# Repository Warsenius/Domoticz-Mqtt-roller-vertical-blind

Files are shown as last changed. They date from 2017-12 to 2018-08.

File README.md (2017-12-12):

# Domoticz-Mqtt-roller-vertical-blind
wifi controlled window blinds using mqtt controlled by domoticz

This is my automated window blinds project that lets Domoticz open and close my vertical blinds.
A steppermotor is controlled by a Wemos D1 mini which receives its commands from Domoticz using MQTT over wifi.

A MQTT server is needed for Domoticz and the Wemos board to connect to.
To set this up please see the the [Domoticz wiki](https://www.domoticz.com/wiki/MQTT)

The LamellenStudie_Wemos file is uploaded to the Wemos board.

In domoticz a Virtual switch is created (named LamellenStudie in this code) of type Blinds Percentage.
This switch is assigned to a floorplan(example) and to a roomplan(Lamellen).
Domoticz will then send out any any changes done to the Virtual switch to the MQTT topic domoticz/out/example/Lamellen where the Wemos board will subscribe to.

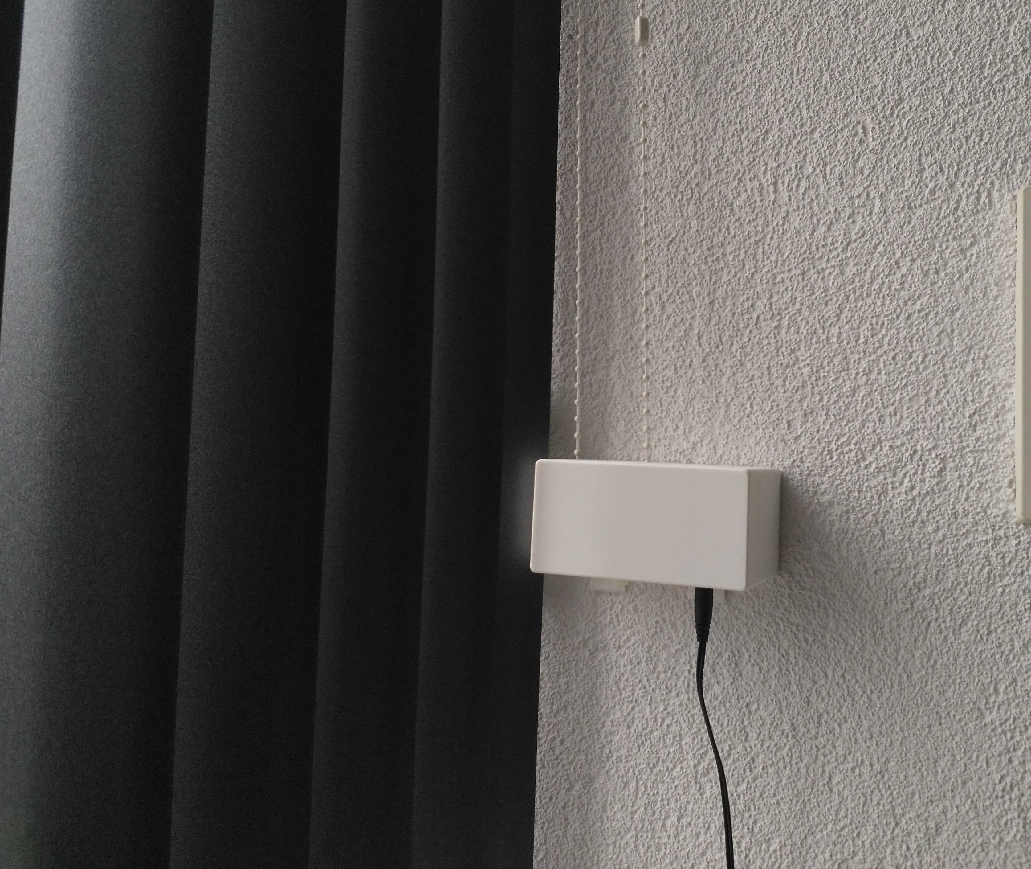
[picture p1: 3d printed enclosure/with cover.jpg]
finished product


## Connecting the parts

I am using the following parts:
1. Wemos D1 mini
1. EasyDriver - Stepper Motor Driver
1. 12 to 5 volt converter [Fine](https://blog.yavilevich.com/2017/03/efficient-dc-12v-to-5v-conversion-for-low-power-electronics-evaluation-of-six-modules/)
1. 2.1 DC power socket
1. 17HS2408 4-lead Nema 17 Steppermotor
1. N/O reed switch (normal open)
1. [Parametric ball chain pulley](https://www.thingiverse.com/thing:3147)
1. [3D printed case](https://github.com/Warsenius/Domoticz-Mqtt-roller-vertical-blind/tree/master/3d%20printed%20enclosure)
1. Tesa powerstrip (to mount case to wall)

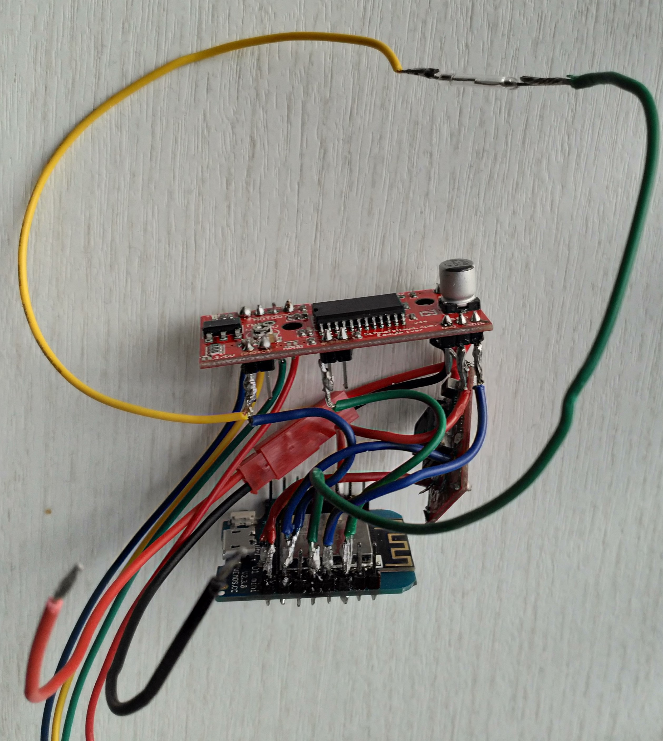
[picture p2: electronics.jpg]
Electronics


The Easydriver board has a build in 12 to 5 volt converter, however it gets really warm and using the Fine converter lowered to idle power usage from 0.11 to 0.04 ampere (at 12volt)

The reed switch is optional, it works as a stop limit using a tiny magnet on the ball chain.

## Follow the Sun

In domoticz i have set up the script "[script_device_blinds_follow_sun_script.lua](https://github.com/Warsenius/Domoticz-Mqtt-roller-vertical-blind/blob/master/script_device_blinds_follow_sun_script.lua)"
This will use the [angle of the sun](http://www.domoticz.com/wiki/Real-time_solar_data_without_any_hardware_sensor_:_azimuth,_Altitude,_Lux_sensor...) and [strenght of the sun](https://www.domoticz.com/wiki/Virtual_weather_devices) (pulled from Weather Underground) to turn the blinds.
It also changes the angle of the blinds if the tv\pc is on and checks if the 'Lamellen Handmatig' virtual switch is on (disabling the script)

the code include's a 'privacy' virtual switch which will close the blinds to position 2 or 14(depending on what is closest) when enabled.

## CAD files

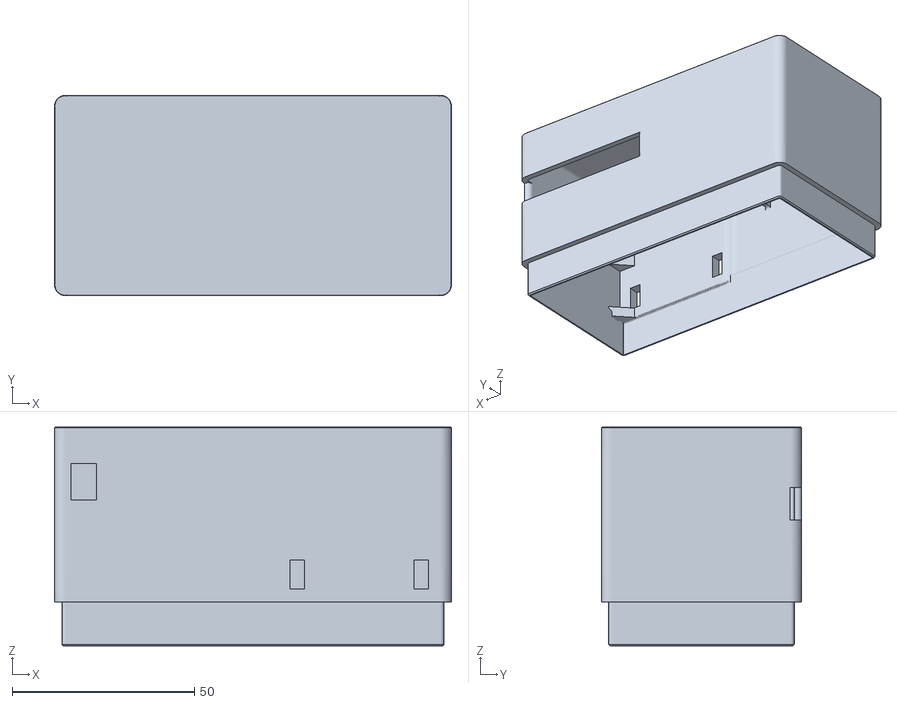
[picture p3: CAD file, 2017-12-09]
3d printed enclosure/Bodem v6.stl
109.0 x 55.0 x 60.0

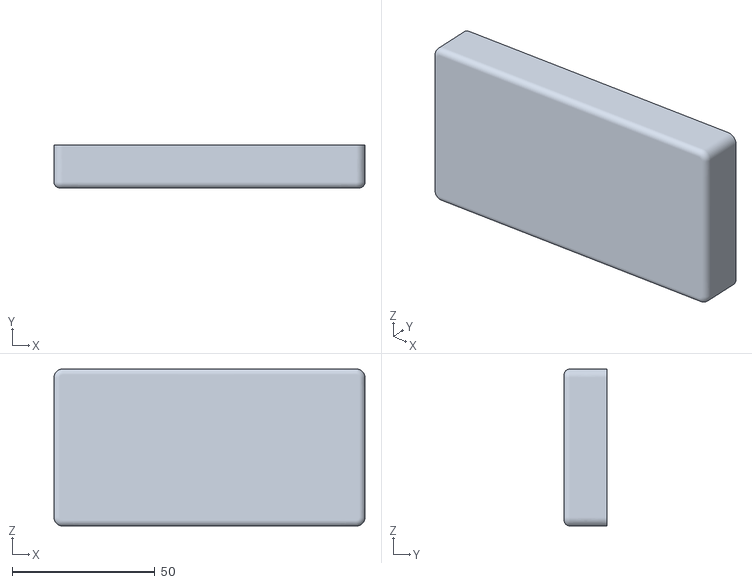
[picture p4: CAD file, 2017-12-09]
3d printed enclosure/Deksel v6.stl
109.0 x 15.0 x 55.0

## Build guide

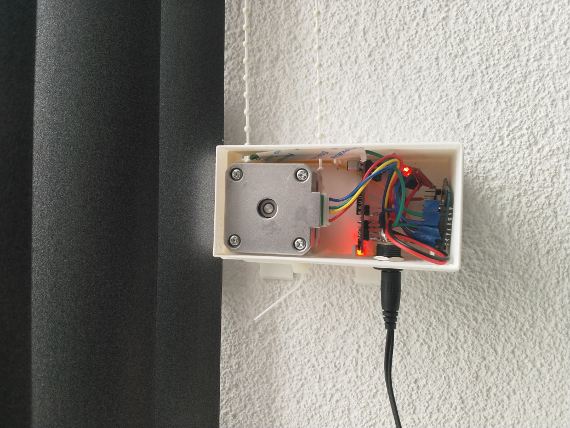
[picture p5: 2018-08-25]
3d printed enclosure/full case_lowres.jpg

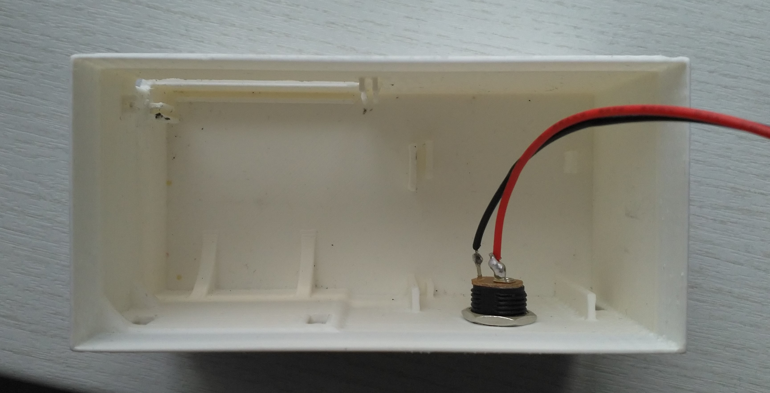
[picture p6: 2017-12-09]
3d printed enclosure/empty case.jpg

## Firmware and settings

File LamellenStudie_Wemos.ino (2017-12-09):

#include <ESP8266WiFi.h>
#include <PubSubClient.h>

// Update these with values suitable for your network.
const char* ssid = "SSID_name";
const char* password = "SSID_password";
const char* mqtt_server = "192.168.123.123";

const char* MQTTclientID = "ESP8266Client-LamellenStudie";
const char* MQTTusername = "MQTT_username";
const char* MQTTpassword = "MQTT_password";

//define the pins used on your wemos board
const int stp = 16;
const int dir = 4;
const int Sleep = 5; 
const int Sensor = 0;

const int StepperRange = 4000; //how many steps does it take to fully close\open\turn your blinds

int Speed = 5; 
int Speedcounter = 0;
int StepperCount = 0;


WiFiClient espClient;
PubSubClient client(espClient);
long lastMsg = 0;
char msg[50];
int value = 0;
void setup_wifi() {
   delay(100);
  // We start by connecting to a WiFi network
    Serial.print("Connecting to ");
    Serial.println(ssid);
    WiFi.begin(ssid, password);
    while (WiFi.status() != WL_CONNECTED) 
    {
      delay(500);
      Serial.print(".");
    }
  randomSeed(micros());
  Serial.println("");
  Serial.println("WiFi connected");
  Serial.println("IP address: ");
  Serial.println(WiFi.localIP());
}

void callback(char* topic, byte* payload, unsigned int length)  {
  byte* p = (byte*)malloc(length);
  memcpy(p,payload,length);
  Serial.print("Message arrived [");
  Serial.print(topic);
  Serial.print("]");
  
  String StringPayload = ""; //convert byte payload to string StringPayload
  for (int i=0;i<length;i++) {
    Serial.print((char)payload[i]);
    StringPayload = StringPayload+(char)payload[i];
  }
  
  if (strcmp(topic, "domoticz/out/example/Lamellen") == 0 ) {  //check the topic\room, in domoticz your device needs to be in a roomplan
    int svalue1, loc, StepperTarget;
    String sub, devicename;
      
    loc = StringPayload.indexOf("name"); //see if there is a name string in the payload and write value to string devicename
    if (loc >= 0){ 
      devicename = StringPayload.substring(loc+9, loc+23); //these locations depend on the name of your switch in domoticz
      Serial.println(devicename);
      
      if (devicename == "LamellenStudie"){  
        loc = StringPayload.indexOf("svalue1"); //see if there is a svalue1 string in the payload    
        if (loc >= 0){ 
          sub = StringPayload.substring(loc+12, loc+14);
          svalue1 = sub.toInt();
          /*Serial.println(loc);
          Serial.println(sub);
          Serial.println(svalue1);
          */}
        
        if (svalue1 >= 0 && svalue1 < 16){ // if svalue1 is in range 0-15 run Stepperset 
          StepperTarget = map(svalue1, 0, 15, 0, StepperRange);
          if (StepperTarget != StepperCount){
            Serial.println(StepperTarget);
            StepperSet(StepperTarget);  
          }
        }
      }
    }
  }
  free(p);
} //end callback

void reconnect() {
  // Loop until we're reconnected
  while (!client.connected()) 
  {
    Serial.print("Attempting MQTT connection...");
    // Create a random client ID
    //clientId += String(random(0xffff), HEX);
    // Attempt to connect
    //if you MQTT broker has clientID,username and password
    //please change following line to    if (client.connect(clientId,userName,passWord))
    //if (client.connect(clientId.c_str()))
    if (client.connect(MQTTclientID, MQTTusername, MQTTpassword)){
      Serial.println("connected");
     //once connected to MQTT broker, subscribe command if any
      client.subscribe("domoticz\/out\/example\/Lamellen");//enter the roomplan name used in domoticz
    } else {
      Serial.print("failed, rc=");
      Serial.print(client.state());
      Serial.println(" try again in 5 seconds");
      delay(6000); // Wait 6 seconds before retrying
    }
  }
} //end reconnect()

void setup() {
  Serial.begin(115200);
  setup_wifi();
  client.setServer(mqtt_server, 1883);
  client.setCallback(callback);
  pinMode(stp, OUTPUT);
  pinMode(dir, OUTPUT);
  pinMode(Sleep, OUTPUT);
  pinMode(Sensor, INPUT_PULLUP);
  digitalWrite(stp, LOW);
  digitalWrite(dir, LOW);
  digitalWrite(Sleep, LOW);
 
}

void loop() {
  if (!client.connected()) {
    reconnect();
  }
  client.loop();
}

void StepperSet(int p1){
  digitalWrite(Sleep, HIGH);
  Serial.println("sleep is high");
  while (StepperCount > p1){
    StepperCCW(); 
  }
  while (StepperCount < p1){
    StepperCW();
  }
  digitalWrite(Sleep, LOW);
  Serial.println("sleep is low");
  Speed = 4;
  Serial.println(Speed);
}

void StepperCCW(){
  digitalWrite(dir, HIGH);  // (HIGH = anti-clockwise / LOW = clockwise)
  bool SensorState = digitalRead(Sensor);
  digitalWrite(stp, HIGH);
  delay(Speed);
  digitalWrite(stp, LOW);
  delay(1);
  StepperCount--;
  Speedcounter++;
  if (Speed != 1 and Speedcounter > 70){
    Speed--;
    Speedcounter = 0;
  }
}    

void StepperCW(){
  digitalWrite(dir, LOW);  // (HIGH = anti-clockwise / LOW = clockwise)
  bool SensorState = digitalRead(Sensor);
  if (SensorState == 1){
    digitalWrite(stp, HIGH);
    delay(Speed);
    digitalWrite(stp, LOW);}
  delay(1);
  StepperCount++;
  Speedcounter++;
  if (Speed != 1 and Speedcounter > 70){
    Speed--;
    Speedcounter = 0;
  }
}    

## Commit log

2017-12-09 Create enclosure
2017-12-12 Update script_device_blinds_follow_sun_script.lua
    added privacy feature, when the switch 'privacy' is switched on, the blinds will go to their closest almost-closed position.
    also fixed the turnblinds function maximum range to 15 which matches the domoticz 100% value.
